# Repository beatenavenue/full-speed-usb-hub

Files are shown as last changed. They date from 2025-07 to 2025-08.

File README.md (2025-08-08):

**ATTENTION: THIS PRODUCT NOT YET WORKING**

# SLOWER SPEED USB HUB
4 port USB2.0 HUB limit by full speed (slow like 1.1)
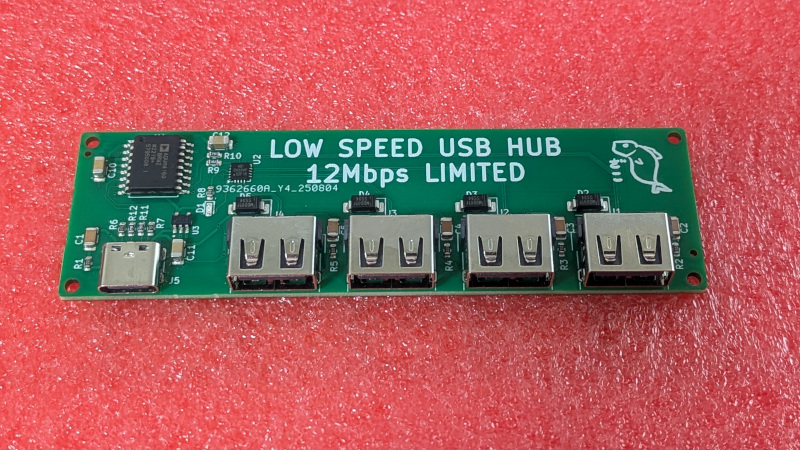
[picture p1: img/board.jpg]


## Motivation
My DIY USB hardware is susceptible to noise and cannot reliably carry high-bit-rate signals over inexpensive jumper wires.  
To work around this, I used a legacy USB 1.1 low-bit-rate device: by inserting a USB 1.1 hub I could force the link to downgrade, which solved the problem completely.  
Unfortunately, USB 1.1 devices are now out of stock, so I can no longer apply the same workaround.

I have recently found a USB 2.0 isolator chip. Although USB 2.0 normally operates at 480 Mbps (Hi-Speed), this chip limits the data rate to 12 Mbps or 1.5 Mbps while still conforming to the USB 2.0 protocol. Because the lower data rate uses lower signalling frequencies, it should mitigate the noise issues just as USB 1.1 did.

## Solution
- **ADuM4160** — USB 2.0 isolator chip  
- **CH334P** — USB 2.0 hub-controller chip

## Dependency Library
- [TLV73330PDBVR](https://www.snapeda.com/parts/TLV73330PDBVR/Texas%20Instruments/view-part/?ref=search&t=TLV73330PDBVR)

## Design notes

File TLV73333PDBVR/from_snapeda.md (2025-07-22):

# Footprint dependency
https://www.snapeda.com/parts/TLV73330PDBVR/Texas%20Instruments/view-part/?ref=search&t=TLV73330PDBVR

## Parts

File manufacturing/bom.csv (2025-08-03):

Designator | Footprint | Quantity | Value | LCSC Part #
C1, C2, C3, C4, C5 | 1206 | 5 | C 0.01uF | C1846
C10, C11, C12 | 1206 | 3 | C 1uF | C1848
D1 | 0603 | 1 | LED | C2286
D2, D3, D4, D5 | D_SMA | 4 | D SS34 C8678 | C8678
J1, J2, J3, J4 | USB_A_Receptacle_C668591 | 4 | USB_A C668591 | C668591
J5 | USB_C_Receptacle_HCTL_HC-TYPE-C-16P-01A | 1 | USB_C_Receptacle_USB2.0_14P | C165948
R1, R2, R3, R4, R5 | 0603 | 5 | R 100k | C25803
R10, R11, R12, R9 | 0603 | 4 | R 27 | C2907018
R6, R7 | 0603 | 2 | R 5.1K | C23186
R8 | 0603 | 1 | R 1K | C21190
U1 | SOIC-16W_7.5x10.3mm_P1.27mm | 1 | ADUM4160 | C579406
U2 | CH334P | 1 | CH334P | C5373042
U3 | SOT95P280X145-5N | 1 | TLV73333PDBVR | C134139

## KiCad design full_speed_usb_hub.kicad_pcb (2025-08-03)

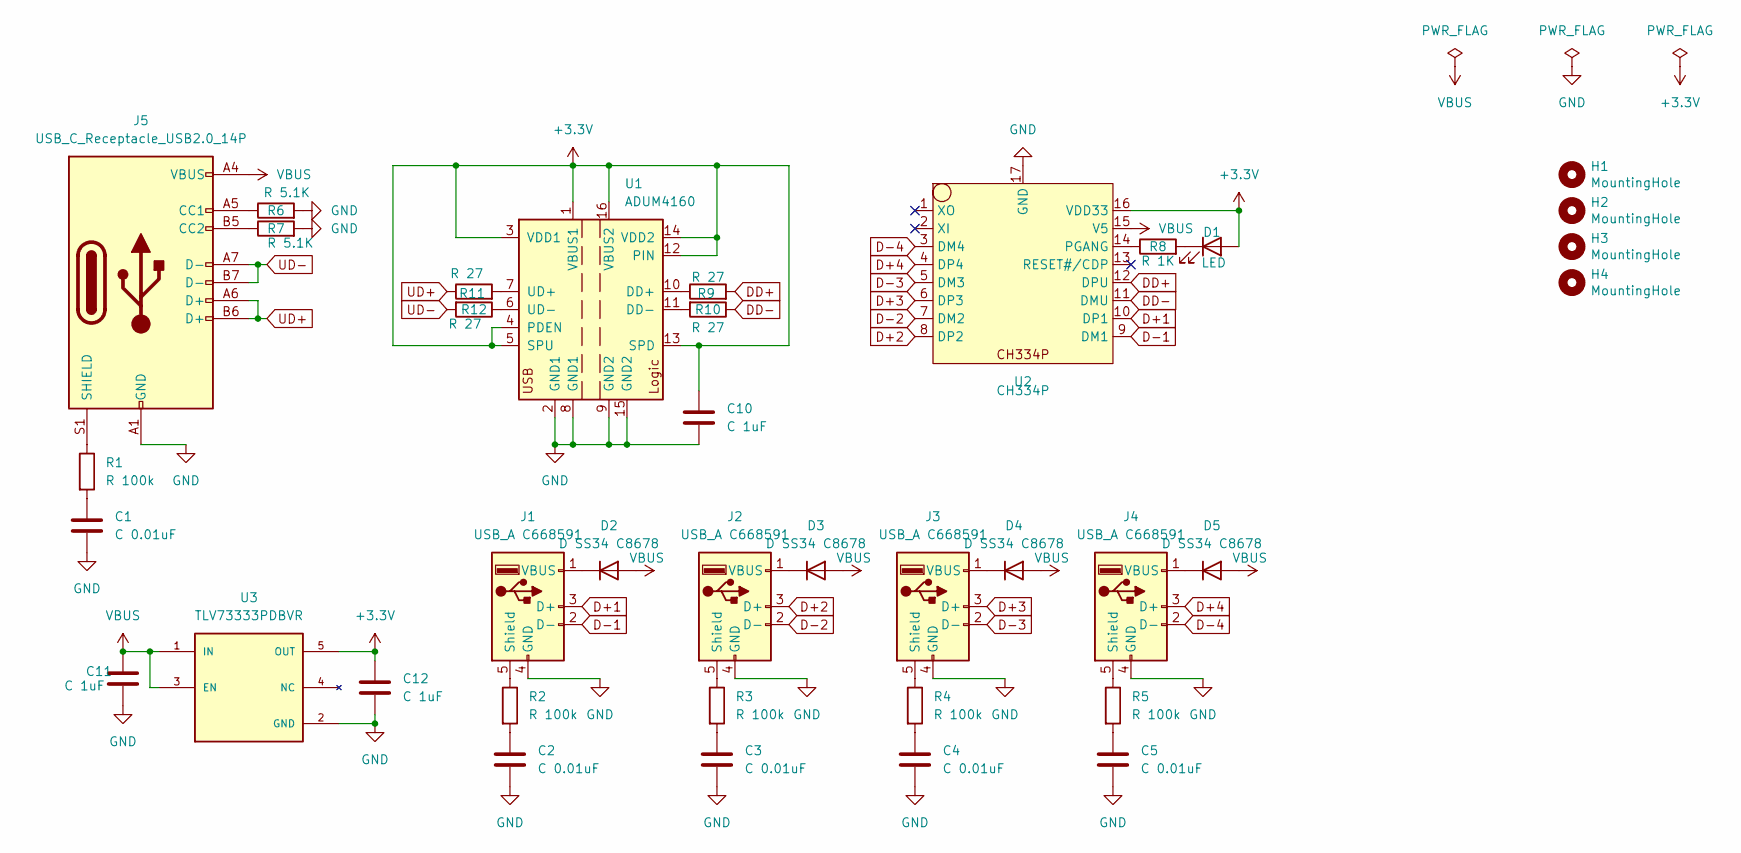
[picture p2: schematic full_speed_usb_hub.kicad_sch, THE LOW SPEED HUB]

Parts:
C1, C2, C3, C4, C5: C 0.01uF; C_1206_3216Metric
C10, C11, C12: C 1uF; C_1206_3216Metric
D1: LED; LED_0603_1608Metric
D2, D3, D4, D5: D SS34 C8678; D_SMA
H1, H2, H3, H4: MountingHole; MountingHole_2.2mm_M2
J1, J2, J3, J4: USB_A C668591; USB_A_Receptacle_C668591
J5: USB_C_Receptacle_USB2.0_14P; USB_C_Receptacle_HCTL_HC-TYPE-C-16P-01A
R1, R2, R3, R4, R5: R 100k; R_0603_1608Metric
R6, R7: R 5.1K; R_0603_1608Metric
R8: R 1K; R_0603_1608Metric
R9, R10, R11, R12: R 27; R_0603_1608Metric
U1: ADUM4160; SOIC-16W_7.5x10.3mm_P1.27mm
U2: CH334P
U3: TLV73333PDBVR; SOT95P280X145-5N; PARTREV C; DigiKey_Part_Number 296-40673-2-ND

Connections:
+3.3V: C10.1, C12.1, D1.2 (A), U1.1 (VBUS1), U1.3 (VDD1), U1.4 (PDEN), U1.5 (SPU), U1.12 (PIN), U1.13 (SPD), U1.14 (VDD2), U1.16 (VBUS2), U2.16 (VDD33), U3.5 (OUT)
D+1: J1.3 (D+), U2.10 (DP1)
D+2: J2.3 (D+), U2.8 (DP2)
D+3: J3.3 (D+), U2.6 (DP3)
D+4: J4.3 (D+), U2.4 (DP4)
D-1: J1.2 (D-), U2.9 (DM1)
D-2: J2.2 (D-), U2.7 (DM2)
D-3: J3.2 (D-), U2.5 (DM3)
D-4: J4.2 (D-), U2.3 (DM4)
DD+: R9.2, U2.12 (DPU)
DD-: R10.1, U2.11 (DMU)
GND: C1.2, C2.2, C3.2, C4.2, C5.2, C10.2, C11.2, C12.2, J1.4 (GND), J2.4 (GND), J3.4 (GND), J4.4 (GND), J5.A1 (GND), J5.A12 (GND), J5.B1 (GND), J5.B12 (GND), R6.2, R7.2, U1.2 (GND1), U1.8 (GND1), U1.9 (GND2), U1.15 (GND2), U2.17 (GND), U3.2 (GND)
unnamed: C1.1, R1.2
unnamed: C2.1, R2.2
unnamed: C3.1, R3.2
unnamed: C4.1, R4.2
unnamed: C5.1, R5.2
unnamed: D1.1 (K), R8.2
unnamed: D2.1 (K), J1.1 (VBUS)
unnamed: D3.1 (K), J2.1 (VBUS)
unnamed: D4.1 (K), J3.1 (VBUS)
unnamed: D5.1 (K), J4.1 (VBUS)
unnamed: J1.5 (Shield), R2.1
unnamed: J2.5 (Shield), R3.1
unnamed: J3.5 (Shield), R4.1
unnamed: J4.5 (Shield), R5.1
unnamed: J5.A5 (CC1), R6.1
unnamed: J5.B5 (CC2), R7.1
unnamed: J5.S1 (SHIELD), R1.1
unnamed: R9.1, U1.10 (DD+)
unnamed: R10.2, U1.11 (DD-)
unnamed: R11.2, U1.7 (UD+)
unnamed: R12.1, U1.6 (UD-)
unnamed: R8.1, U2.14 (PGANG)
UD+: J5.A6 (D+), J5.B6 (D+), R11.1
UD-: J5.A7 (D-), J5.B7 (D-), R12.2
VBUS: C11.1, D2.2 (A), D3.2 (A), D4.2 (A), D5.2 (A), J5.A4 (VBUS), J5.A9 (VBUS), J5.B4 (VBUS), J5.B9 (VBUS), U2.15 (V5), U3.1 (IN), U3.3 (EN)

Board: 2 copper layers, 37 parts (0 on the bottom side), 37 nets, no tracks yet.

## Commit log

2025-07-22 KiCAD Design
    [full_speed_usb_hub.kicad_pcb, full_speed_usb_hub.kicad_sch]
2025-08-03 update BOM and order PCBA
    [bom.csv, full_speed_usb_hub.kicad_pcb, full_speed_usb_hub.kicad_sch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]
2025-08-08 add pcba image
